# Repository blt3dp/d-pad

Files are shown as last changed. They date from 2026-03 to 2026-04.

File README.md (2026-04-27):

# D-Pad: A Handheld Framework Gaming PC
Start with a 3D printed case, add some laptop parts from Framework Computer Inc [https://frame.work/](https://frame.work/) as well as some other electronics and hardware and what do you have?  A fully customizable, fully upgradeable, and fully repairable handheld gaming PC that you can make your own!

## Features
Able to use any Framework 13 Motherboard and Battery  
8.9" IPS Touchscreen  
Front facing speakers  
Joycon docking/charging  
Framework Expansion Card compatibility  
Docking station connector  
Power and volume buttons  
Kickstand  
Additional expansion provisions

## Building Your Own
The build process is outlined in a YouTube video [https://www.youtube.com/watch?v=xQa__ukKvmM](https://www.youtube.com/watch?v=xQa__ukKvmM)  
I recommend watching it completely at least once to get an idea of how D-Pad is assembled.

You'll find all the information you need to build one in this repository.

## Pics
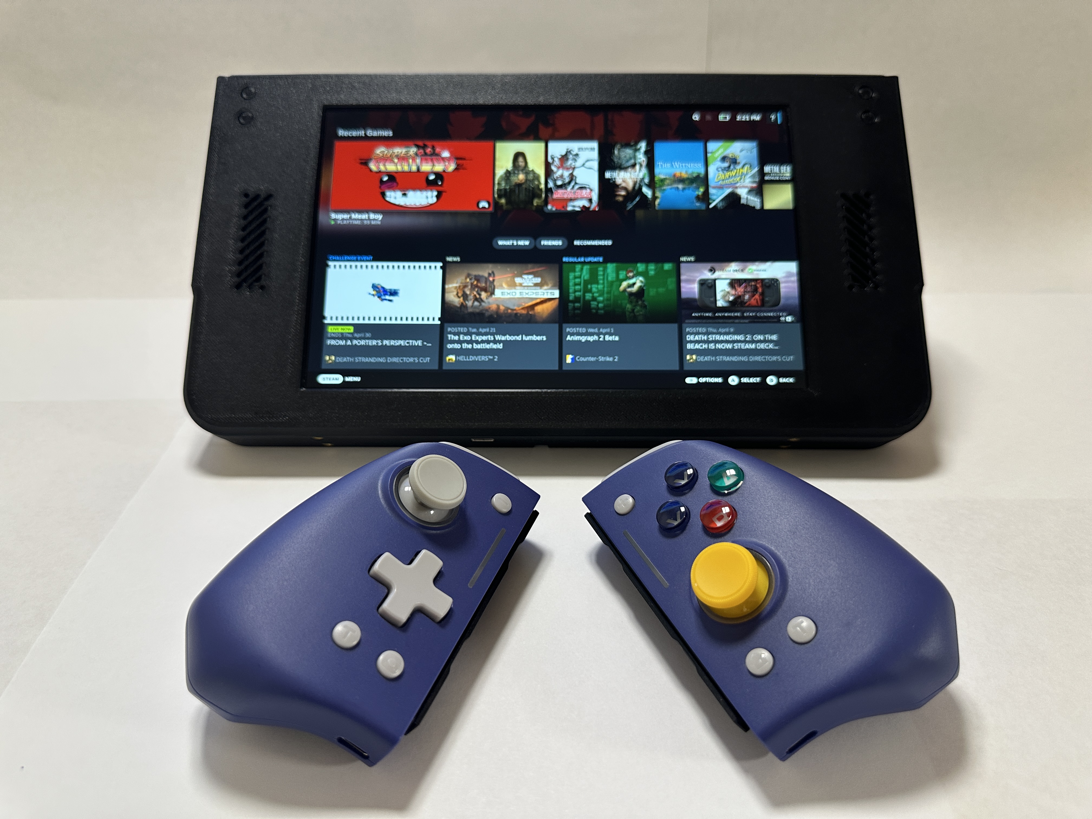
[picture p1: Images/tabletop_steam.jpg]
tabletop_steam_image

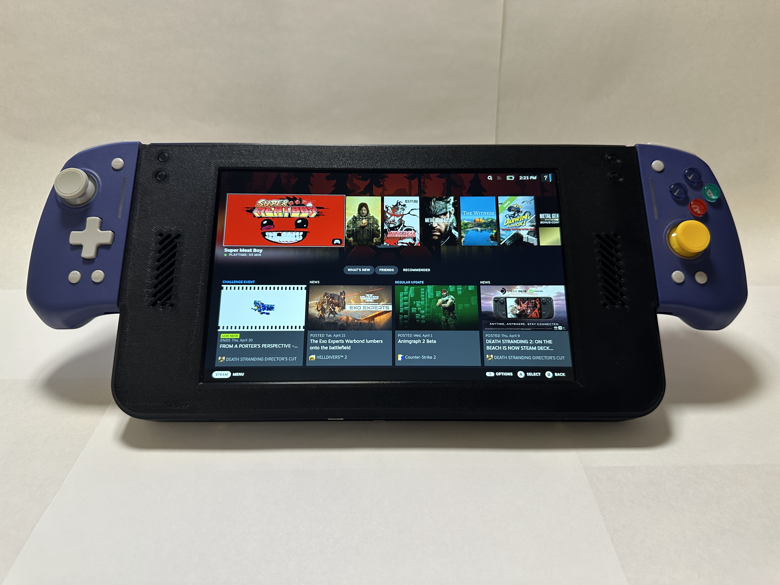
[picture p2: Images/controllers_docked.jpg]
controllers_docked_image

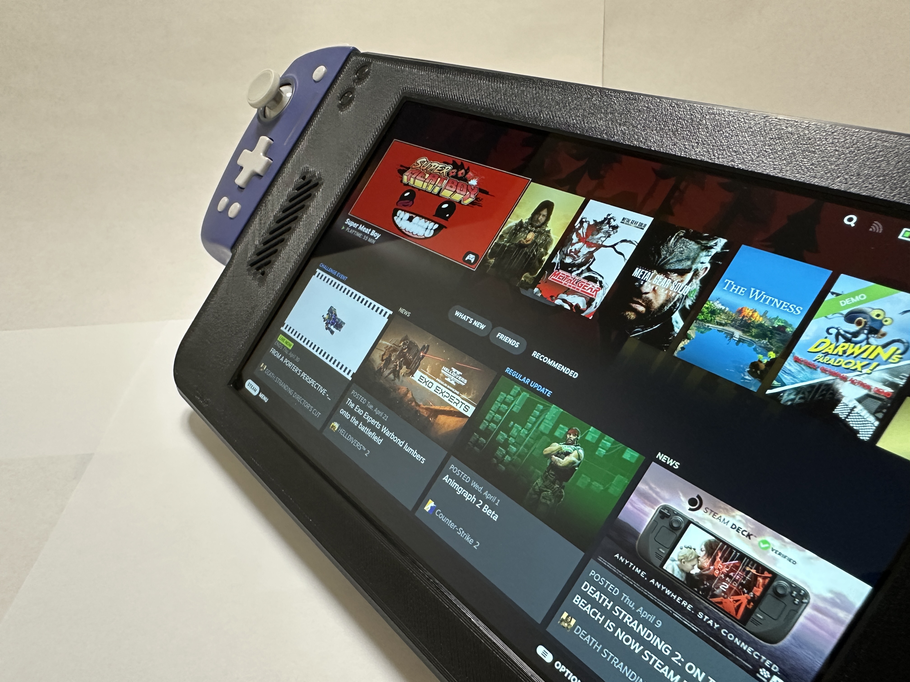
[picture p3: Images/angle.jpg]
angle_image

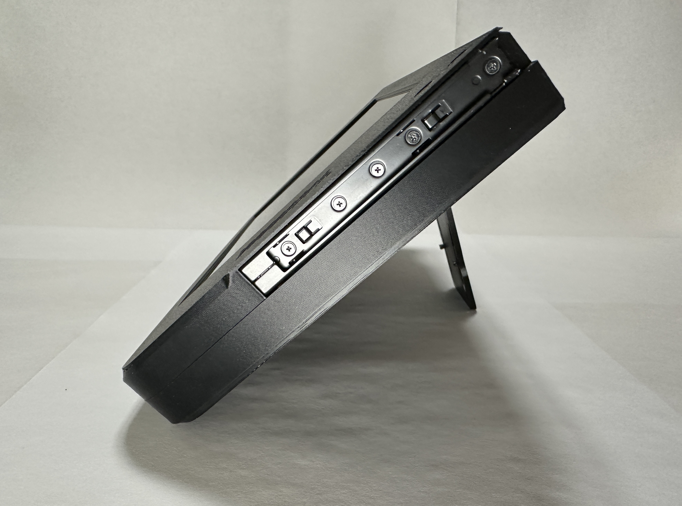
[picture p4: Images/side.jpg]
side_image

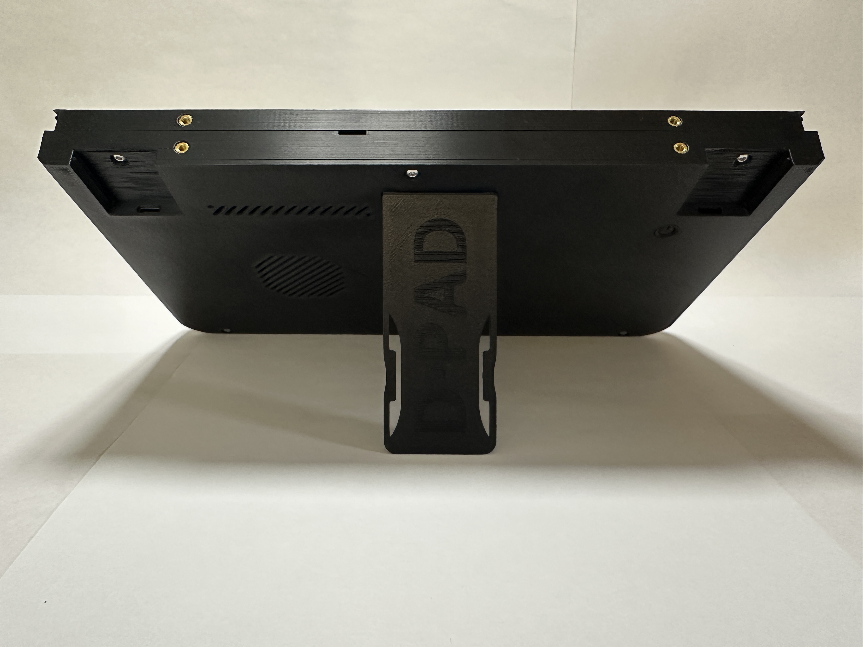
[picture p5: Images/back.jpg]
back_image


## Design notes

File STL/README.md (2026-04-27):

# D-Pad STL files

Please follow one of the links below to obtain the STL files for the D-Pad.

[https://thangs.com/designer/blt3dp/3d-model/D-Pad%3A%20A%20Handheld%20Framework%20Gaming%20PC-1543758](https://thangs.com/designer/blt3dp/3d-model/D-Pad%3A%20A%20Handheld%20Framework%20Gaming%20PC-1543758)

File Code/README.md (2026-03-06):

# D-Pad volume control HID device

This folder contains instructions and code that you will upload to the RP2040 for it to function as a volume control HID device.

### Installing CircuitPython 

The software is written in CircuitPython 10.x and uses the HID module of CircuitPython Library Bundle.

1. Download the latest stable 10.x CircuitPython UF2 from the official website [here](https://circuitpython.org/board/pimoroni\_tiny2040/).

2. Push and hold the BOOTSEL button and plug your Tiny 20240 into the USB port of your computer. Release the BOOTSEL button after your microcontroller is connected.

3. It will mount as a Mass Storage Device called RPI-RP2.

4. Drag and drop the CircuitPython UF2 file onto the RPI-RP2 volume. 

### Installing HID libraries

1. Download the library bundle for the CircuitPython version you installed 10.x from [here](https://circuitpython.org/libraries).

2. Unzip the bundle; Copy `adafruit\_hid` from the `lib` folder to `<CIRCUITPY DRIVE>/lib/`.

### Software installation

1. Download the 2 .py files from this folder.

2. Place them in the root of the \<CIRCUITPY DRIVE>.

   2a. The code should immediately run and begin functioning as a volume up (GP28) and volume down (GP29) when either are bridged to ground.
   
   2b. The boot.py will stop the <CIRCUITPY DRIVE> from mounting on the next boot.  It does make it more difficult to edit the code if you wish to.  If you need to access the code, hold the volume up (GP28) button while powering on the system and it will mount the \<CIRCUITPY DRIVE>.

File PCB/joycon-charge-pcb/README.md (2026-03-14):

# Joycon charge PCB

This folder contains the KiCad files for the optional front buttons for system power, monitor

power, volume up, and volume down.

Have these boards made by a PCB manufacturer of your choice.  Solder on a 2 conductor wire

as well as a FH36W-11S-0.3SHW(99), available here:

[https://www.digikey.com/en/products/detail/hirose-electric-co-ltd/FH36W-11S-0-3SHW-99/4168641](https://www.digikey.com/en/products/detail/hirose-electric-co-ltd/FH36W-11S-0-3SHW-99/4168641)

Here's what you should end up with when completed.

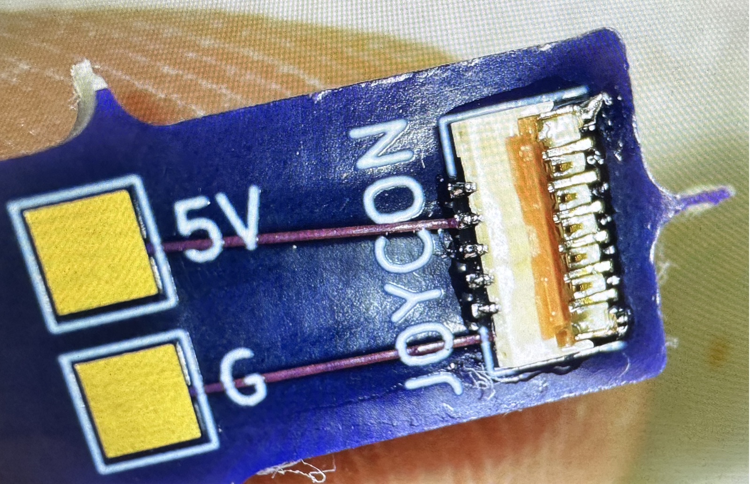
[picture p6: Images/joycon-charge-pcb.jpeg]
joycon-charge-pcb image


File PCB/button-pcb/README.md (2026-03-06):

# D-Pad front buttons PCB

This folder contains the KiCad files for the optional front buttons for system power, monitor

power, volume up, and volume down.

Have these boards made by a PCB manufacturer of your choice.  Solder as many buttons as you

plan to use.  These are designed for through hole tact switches measuring 6x6x5mm.  I used

these

[https://www.amazon.com/dp/B07X8T9D2Q](https://www.amazon.com/dp/B07X8T9D2Q)

If you are using this for the volume up and volume down buttons, bridge the jumper pads and

attach a 3 conductor wire.

If you are using this for system power and monitor power, DO NOT bridge the jumper pads and

attach a 4 conductor wire.

Here's what you should end up with when completed.

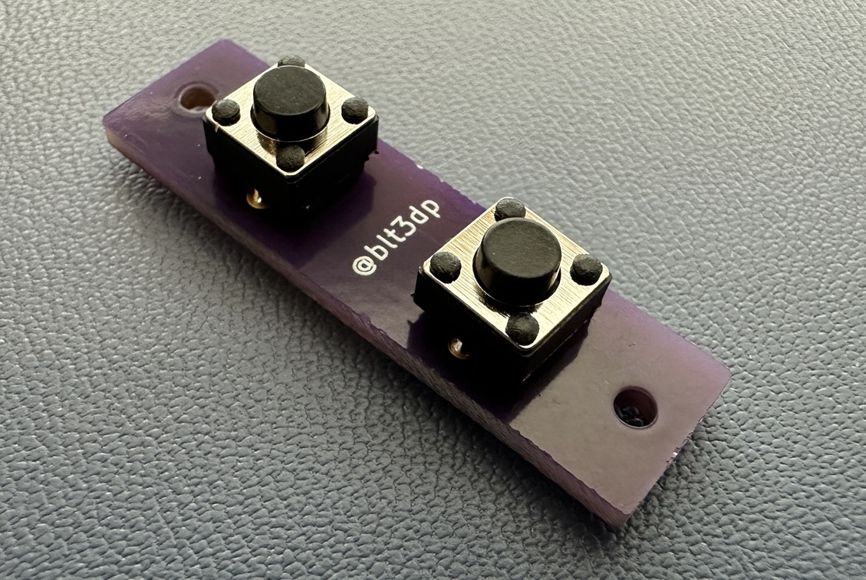
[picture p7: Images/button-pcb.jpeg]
button-pcb image


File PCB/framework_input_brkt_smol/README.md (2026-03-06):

# Original input shim by CRImer

This is a copy of the files for the Framework input shim by CRImer.  I decided to copy them as I

didn't want to clone the entire repository they were in.

The original source for the files can be found here:

[https://github.com/CRImier/MyKiCad/tree/master/Laptop%20mods/framework\_input\_brkt\_smol](https://github.com/CRImier/MyKiCad/tree/master/Laptop%20mods/framework_input_brkt_smol)

Also below is the original README.md content

\*\*\*\*\*\*\*\*\*\*\*\*\*\*\*\*\*\*\*\*\*\*\*\*\*\*\*\*\*\*\*\*\*\*\*\*\*\*\*\*\*\*\*\*\*\*\*\*\*\*\*\*\*\*\*\*\*\*\*\*\*\*\*\*\*\*\*\*\*\*\*\*\*\*\*\*\*\*\*\*\*\*\*\*\*\*\*\*\*\*\*\*\*\*\*\*\*

# Framework input shim

This is a small shim for the Framework laptop motherboard. It exposes the power button,
a USB port with 5V power, keyboard backlight, Caps Lock and fingerprint LED connections.
It is designed to fit inside the outline of the input connector FPC plug,
within the motherboard outline, so that it can easily be added to existing designs.

For wire connections, this shim uses THT holes, since it's relatively easy to rip
an SMD pad off the board by pulling on a wire. This [requires some kapton fixes](../../Images/input-kapton.jpeg)
during assembly, however.

Markings on the PCB: "FrmW input brkt" (shortened because the board has to be very small)

Connector used: Amphenol 10156001-051100LF

These are KiCad 5 files - will be updated to KiCad 6 sometime later.

\#Changes in v3:

* Updated to KiCad 6
* Updated soldermask on connector soldering layer to decrease chances of THT-to-connector shorts
* Cosmetic: removed between-pin traces on a GND group of pins
* Adjusted traces so that there's less visual "shorts"

# Changes in v2:

The input connector symbol numbering was incorrect
and v1 of this adapter could break your mobo or something.

* Signal names are silkscreened on the board's top layers.
* Software: Kicad 6
* Version: 2
* PCB size: 18x7.75
* Layer count: 2

\*\*\*\*\*\*\*\*\*\*\*\*\*\*\*\*\*\*\*\*\*\*\*\*\*\*\*\*\*\*\*\*\*\*\*\*\*\*\*\*\*\*\*\*\*\*\*\*\*\*\*\*\*\*\*\*\*\*\*\*\*\*\*\*\*\*\*\*\*\*\*\*\*\*\*\*\*\*\*\*\*\*\*\*\*\*\*\*\*\*\*\*\*\*\*\*\*

Also, here's CRImer's wiring drawing.

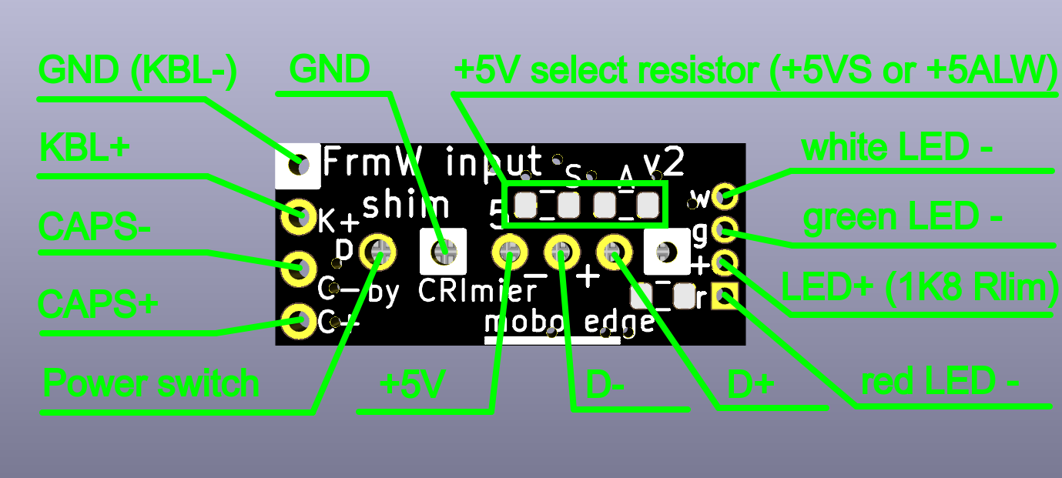
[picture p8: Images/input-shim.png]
input-shim image


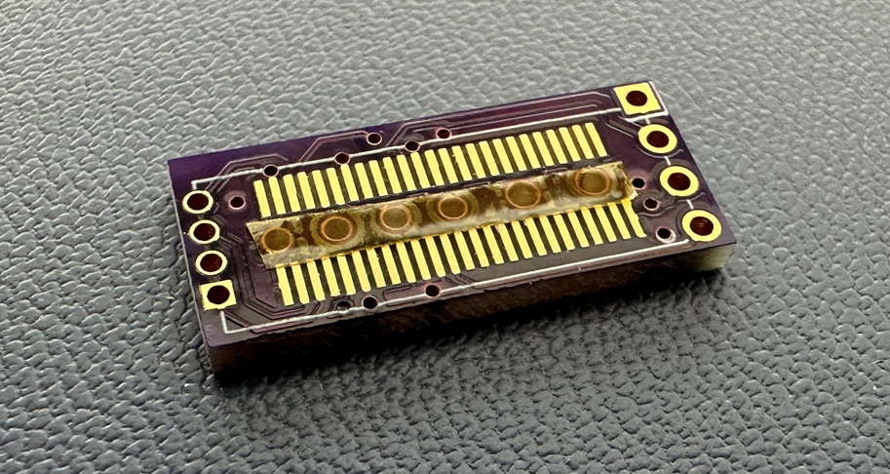
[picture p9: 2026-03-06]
Images/input-kapton.jpeg

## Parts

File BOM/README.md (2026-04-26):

# D-Pad Bill of Materials

## Core System
Below is a listing of all the parts required to build a D-Pad as well as the parts needed for optional quality of life features.  There is one part that falls in-between and a decision you'll have to make.

### Choose at least one external USB connector. The rest are optional.

Docking Connector - ADT Link T6A-T8T-NC, 30cm [https://www.aliexpress.us/item/3256804442407128.html](https://www.aliexpress.us/item/3256804442407128.html)  
Left Expansion Port Connector - ADT Link T7B-T6A, 15cm [https://www.aliexpress.us/item/3256805100333291.html](https://www.aliexpress.us/item/3256805100333291.html)  
Right Expansion Port Connector - ADT Link T7B-T6A, 15cm [https://www.aliexpress.us/item/3256805100333291.html](https://www.aliexpress.us/item/3256805100333291.html)

### Plastics (Required) - See STL folder
casing-front.stl  
screen-clamp.stl  
batt-mobo-mount-l.stl  
batt-mobo-mount-r.stl  
wifi-mount.stl  
kickstand.stl  
kickstand-clamp.stl  
casing-back.stl  
power-button.stl  

### Electronics (Required)
(1) Wisecoco 9 Inch 2560x1600 2K LCD [https://www.aliexpress.us/item/3256804988426586.html](https://www.aliexpress.us/item/3256804988426586.html)  
(1) ADT Link T6A-T6B, 10m [https://www.aliexpress.us/item/3256804434450164.html](https://www.aliexpress.us/item/3256804434450164.html)  
(1) Framework 13 Speaker Set [https://frame.work/products/speaker-kit?v=FRANBX0001](https://frame.work/products/speaker-kit?v=FRANBX0001)  
(1) Breakout for JST SH-Style Connector, 4-Pin Male Side-Entry [https://www.digikey.com/en/products/detail/pololu/4815/26813865](https://www.digikey.com/en/products/detail/pololu/4815/26813865)  
(1) JST SH-Style Cable, 4-Pin, Single-Ended Female, 30cm [https://www.digikey.com/en/products/detail/pololu/5521/26752073](https://www.digikey.com/en/products/detail/pololu/5521/26752073)  
(1) WiFi Antenna Set [https://www.amazon.com/dp/B0CJDVZYWF](https://www.amazon.com/dp/B0CJDVZYWF)  
(1) Framework 13 Battery (55Wh or 61Wh) [https://frame.work/products/battery?v=FRANGWAT01](https://frame.work/products/battery?v=FRANGWAT01)  
(1) Framework 13 Motherboard [https://frame.work/marketplace/mainboards?search=Framework+Laptop+13+Mainboard\&brand%5B%5D=framework](https://frame.work/marketplace/mainboards?search=Framework+Laptop+13+Mainboard&brand%5B%5D=framework)  
(1) Your choice of RAM, Storage and WiFi/Bluetooth Adapter.  
(1) Your choice of external USB connector from above.  

### Hardware (Required)
(1) Joycon Rail Set (remove flex cables if not doing optional charging) [https://www.amazon.com/dp/B08CZ1DD83](https://www.amazon.com/dp/B08CZ1DD83)  
(15) M3x5x4 Brass Heatset Insert [https://www.amazon.com/dp/B0CDH36ZMX](https://www.amazon.com/dp/B0CDH36ZMX)  
(11) M1.6x2.5x4 Brass Heatset Insert [https://www.amazon.com/dp/B07TTQXVQH](https://www.amazon.com/dp/B07TTQXVQH)  
(2) M5 Flat Washers
(3) M3x10 Button Head Cap Screws  
(2) M3x16 Button Head Cap Screws  
(4) M3x20 Button Head Cap Screws  

### Other (Required)
(1) Scotch Mount Double Sided Tape [https://www.amazon.com/dp/B0007P5G8Y](https://www.amazon.com/dp/B0007P5G8Y)
(1) 1/4" Kapton Tape [https://www.amazon.com/dp/B07RL12SGF](https://www.amazon.com/dp/B07RL12SGF)
Misc Tape

# Optional Features
All optional features require wire.  https://www.amazon.com/dp/B07PPT11QN  
All optional features require screws. https://www.ebay.com/itm/144381124719  
All optional features require solder.

## Power Button for Display

### Electronics
(1) button-pcb https://github.com/blt3dp/d-pad/tree/main/PCB/button-pcb  
(1) 6x6x5mm through hole tact switch https://www.amazon.com/dp/B07X8T9D2Q  

### Plastics
(1) opt-button.stl 

### Hardware
(1) M1.6x2.5x4 Brass Heatset Insert [https://www.amazon.com/dp/B07TTQXVQH](https://www.amazon.com/dp/B07TTQXVQH)  

# All remaining optional feature require the Framework Input Shim
(1) Framework Input Shim PCB https://github.com/blt3dp/d-pad/tree/main/PCB/framework\_input\_brkt\_smol  
(1) Amphenol 10156001-051100LF https://www.digikey.com/en/products/detail/amphenol-cs-fci/10156001-051100LF/11688418  

## Power button for Console
BOM same as for display.  If doing both just add a tact switch to the same PCB and print another opt-button.stl  

## Volume Control
### Electronics
(1) button-pcb https://github.com/blt3dp/d-pad/tree/main/PCB/button-pcb  
(2) 6x6x5mm through hole tact switch https://www.amazon.com/dp/B07X8T9D2Q  
(1) Waveshare RP2040-One https://www.amazon.com/dp/B0BLMPDMLD  

### Hardware
(1) M1.6x2.5x4 Brass Heatset Insert [https://www.amazon.com/dp/B07TTQXVQH](https://www.amazon.com/dp/B07TTQXVQH)  

### Plastics
(2) opt-button.stl  

## Joycon Charging
### Electronics
(2) Joycon Charge PCB https://github.com/blt3dp/d-pad/tree/main/PCB/joycon-charge-pcb  
(2) FH36W-11S-0.3SHW(99) https://www.digikey.com/en/products/detail/hirose-electric-co-ltd/FH36W-11S-0-3SHW-99/4168641  

### Hardware
(1) Joycon Rail Set from the required list, with flex cables  
(1) M1.6x2.5x4 Brass Heatset Insert [https://www.amazon.com/dp/B07TTQXVQH](https://www.amazon.com/dp/B07TTQXVQH)

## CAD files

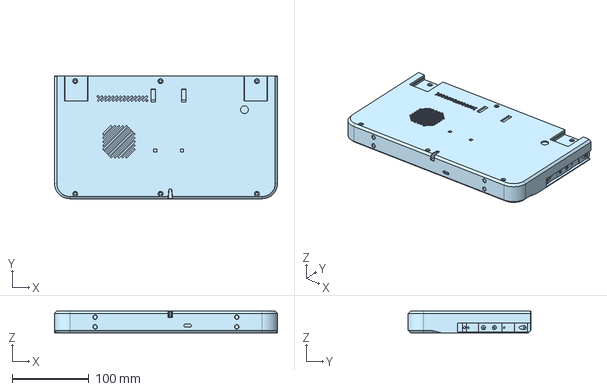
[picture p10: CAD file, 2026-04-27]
CAD/casing-blank.step
290.0 x 159.4 x 28.4 mm

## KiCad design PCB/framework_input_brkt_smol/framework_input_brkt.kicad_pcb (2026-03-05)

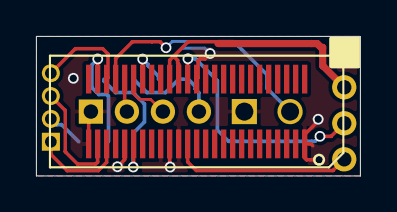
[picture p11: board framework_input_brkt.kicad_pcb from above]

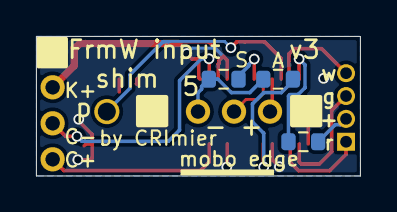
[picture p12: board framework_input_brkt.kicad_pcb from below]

Board: 2 copper layers, 18.0 x 7.8 mm, 8 parts (7 on the bottom side), 15 nets.

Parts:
J1: FPR_LED; PinHeader_1x04_P1.27mm_Vertical
J2: fpc_input_conn; Amphenol_10156001
J3: PWRSW; PinHeader_1x02_P2.54mm_Vertical
J4: USB; PinHeader_1x04_P2.00mm_Vertical
J5: KnC; PinHeader_1x04_P2.00mm_Vertical
R1: 0R; R_0603_1608Metric
R2: NC; R_0603_1608Metric
R3: 560R; R_0603_1608Metric

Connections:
/5VALW: J2.31, R2.2
/5VS: J2.19, R1.1
/CAPS_N: J2.14, J5.3
/CAPS_P_5V: J2.37, J5.4
/FPR_LED_COM_5V: J2.24, R3.1
/FPR_LED_G: J1.3, J2.27
/FPR_LED_R: J1.1, J2.28
/FPR_LED_W: J1.4, J2.23
/KBL_P: J2.15, J2.16, J5.2
/SWITCH: J2.22, J3.2
/USB_N: J2.20, J4.3
/USB_P: J2.21, J4.2
GND: J2.13, J2.26, J2.30, J2.34, J2.35, J2.36, J2.50, J3.1, J4.1, J5.1
unnamed: J1.2, R3.2
unnamed: J4.4, R1.2, R2.1

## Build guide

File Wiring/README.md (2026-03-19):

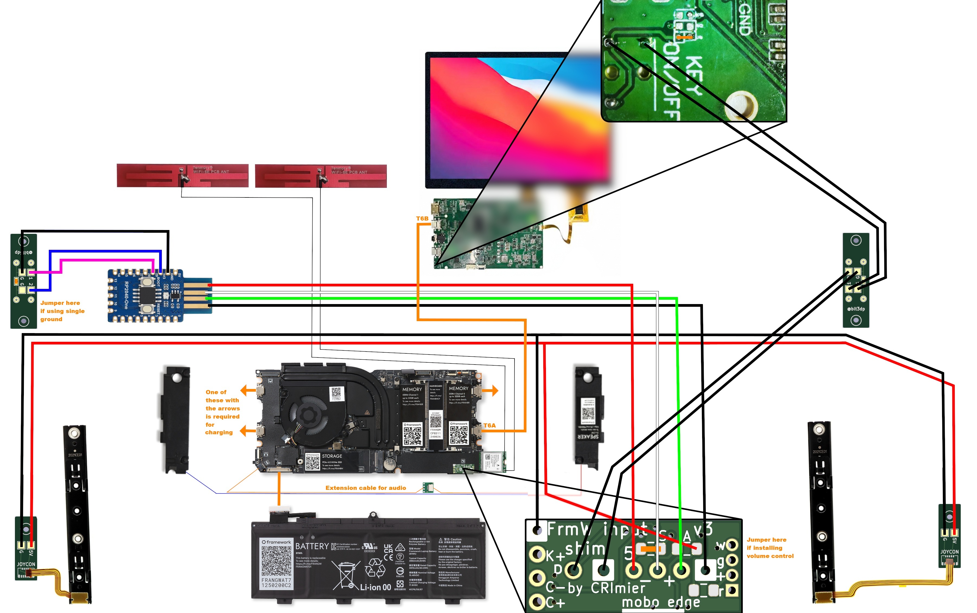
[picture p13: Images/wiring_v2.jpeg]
wiring image


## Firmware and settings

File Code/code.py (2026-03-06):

import time
import digitalio
import board
import usb_hid
from adafruit_hid.consumer_control import ConsumerControl
from adafruit_hid.consumer_control_code import ConsumerControlCode

# Define the pins for the buttons
btn1_pin = board.GP28
btn2_pin = board.GP29

# Create the Keyboard object
consumer = ConsumerControl(usb_hid.devices)

# Set up the buttons
btn1 = digitalio.DigitalInOut(btn1_pin)
btn1.direction = digitalio.Direction.INPUT
btn1.pull = digitalio.Pull.UP

btn2 = digitalio.DigitalInOut(btn2_pin)
btn2.direction = digitalio.Direction.INPUT
btn2.pull = digitalio.Pull.UP

while True:
    # Check if button 1 is pressed
    if not btn1.value:
        consumer.send(ConsumerControlCode.VOLUME_INCREMENT)
        time.sleep(0.1)

    # Check if button 2 is pressed
    if not btn2.value:
        consumer.send(ConsumerControlCode.VOLUME_DECREMENT)
        time.sleep(0.1)

    # Delay to avoid excessive CPU usage
    time.sleep(0.1)

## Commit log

2026-03-05 Add files via upload
    Uploading initial PCB files.
    [button-pcb.kicad_pcb, button-pcb.kicad_sch, framework_input_brkt.kicad_pcb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]
2026-03-05 Add files via upload
    Adding STL folder.
